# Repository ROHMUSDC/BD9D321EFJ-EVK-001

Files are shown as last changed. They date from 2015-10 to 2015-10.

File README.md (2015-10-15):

# BD9D321EFJ-EVK-001 Design Resource Repository
* Hardware Design Files and Documentation for the ROHM BD9D321EFJ-EVK-001 EVK

----
### Description: 
* BD9D321EFJ is a synchronous buck switching regulator with built-in low on-resistance power MOSFETs
* It is capable of providing current of up to 3 A
* The SLLM (TM) control provides excellent efficiency characteristics in light-load conditions which make the product appropriate for equipment and devices that demand minimal standby power consumption
* External phase compensation circuit is not necessary because this device uses a constant on-time control DC/DC converter with high speed response

----
### Repository Contents
* Application Note Folder: Contains Draft Version of EVK Application Note
* Design Files: Contains Board, Gerber, Schematic, and BOM information for this EVK Board

----
### Where to Purchase?
* http://www.rohm.com/web/global/distribution/-/dinventory/BD9D321EFJ-EVK-101/sample/0

----
### DISCLAIMER
This Technical Data is protected under copyright laws.

ROHM hereby grants you a nonexclusive, nontransferable license to use this Technical Data 
as long as you abide by the terms and conditions of this DISCLAIMER. 

However, you are not authorized to sell, loan, rent, lease, redistribute or license this Technical Data, 
in whole or in part, or in modified form, to anyone.

You may modify this Technical Data to suit your specific applications, 
but the rights to derivative works and said modifications shall belong to ROHM. 

You may make copies of this Technical Data as necessary for internal use only within your company.

In any case, the latest datasheet is considered the final design guideline and represents 
the only actual performance specifications.

ROHM shall not be responsible for ensuring proper application on all computer systems.
This Technical Data is provided AS IS. ROHM makes no guarantees, either implicitly or explicitly, 
regarding its usability, functionality, accuracy, merchantability, or fitness for a specific purpose.

In addition, you shall take full responsibility for the use of any information acquired from this Technical Data. 

ROHM does not assume warranty of any kind arising from the use of this Technical Data. ACCORDINGLY, 
IN NO EVENT SHALL ROHM BE RESPONSIBLE, WHETHER THROUGH CONTRACT OR TORT LIABILITY, 
FOR ANY DAMAGES (INCLUDING BUT NOT LIMITED TO LOST PROFITS OR OTHER INCIDENTAL, CONSEQUENTAL, 
OR PUNITIVE DAMAGES) ARISING OUT OF OR IN CONNECTION WITH THE USE OR APPLICATION OF THIS Technical Data.

Furthermore, this Technical Data is subject to change without notice.

Unless otherwise expressly provided herein, ROHM does not convey any license under patent rights 
or any other intellectual property rights (including those of third parties).

ROHM is not obligated to provide maintenance or support for the Technical Data.

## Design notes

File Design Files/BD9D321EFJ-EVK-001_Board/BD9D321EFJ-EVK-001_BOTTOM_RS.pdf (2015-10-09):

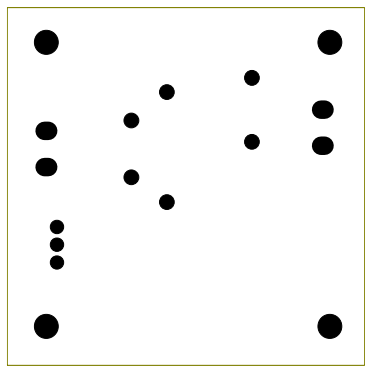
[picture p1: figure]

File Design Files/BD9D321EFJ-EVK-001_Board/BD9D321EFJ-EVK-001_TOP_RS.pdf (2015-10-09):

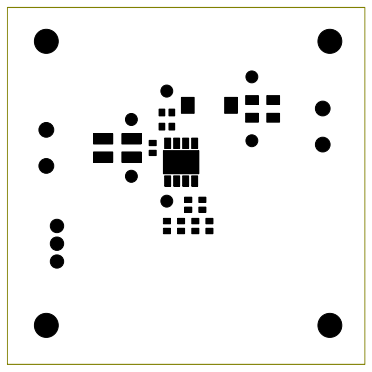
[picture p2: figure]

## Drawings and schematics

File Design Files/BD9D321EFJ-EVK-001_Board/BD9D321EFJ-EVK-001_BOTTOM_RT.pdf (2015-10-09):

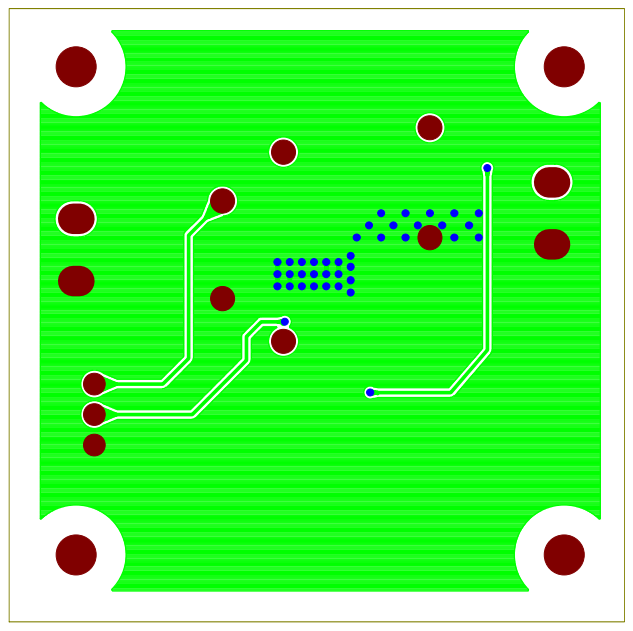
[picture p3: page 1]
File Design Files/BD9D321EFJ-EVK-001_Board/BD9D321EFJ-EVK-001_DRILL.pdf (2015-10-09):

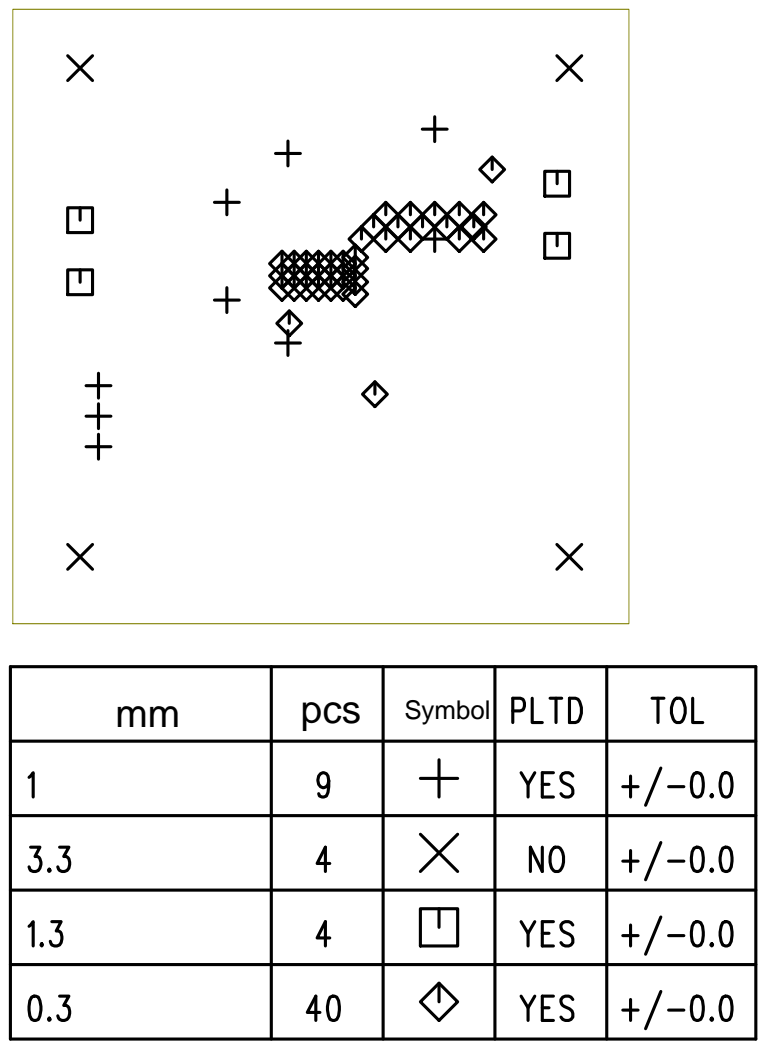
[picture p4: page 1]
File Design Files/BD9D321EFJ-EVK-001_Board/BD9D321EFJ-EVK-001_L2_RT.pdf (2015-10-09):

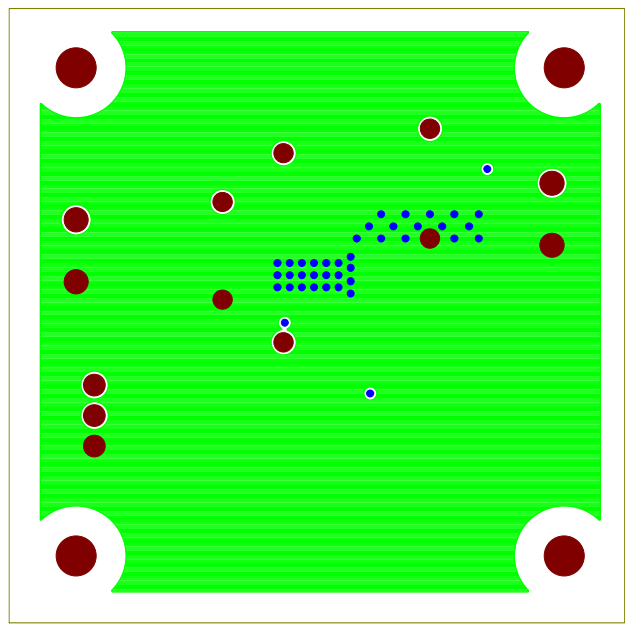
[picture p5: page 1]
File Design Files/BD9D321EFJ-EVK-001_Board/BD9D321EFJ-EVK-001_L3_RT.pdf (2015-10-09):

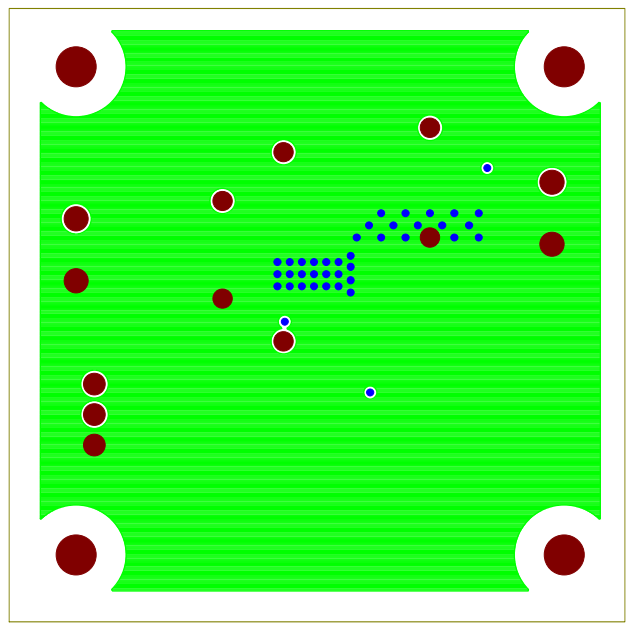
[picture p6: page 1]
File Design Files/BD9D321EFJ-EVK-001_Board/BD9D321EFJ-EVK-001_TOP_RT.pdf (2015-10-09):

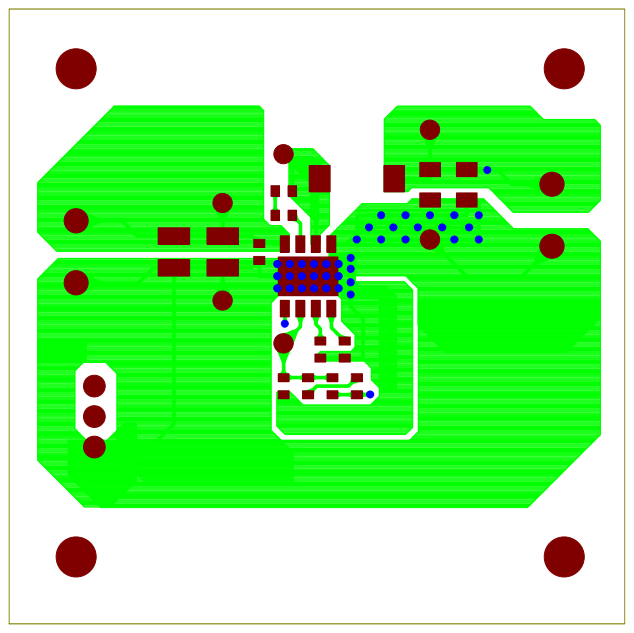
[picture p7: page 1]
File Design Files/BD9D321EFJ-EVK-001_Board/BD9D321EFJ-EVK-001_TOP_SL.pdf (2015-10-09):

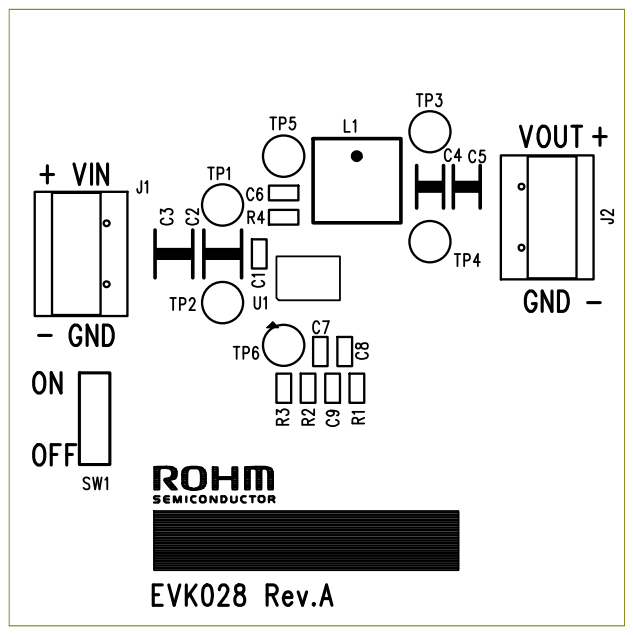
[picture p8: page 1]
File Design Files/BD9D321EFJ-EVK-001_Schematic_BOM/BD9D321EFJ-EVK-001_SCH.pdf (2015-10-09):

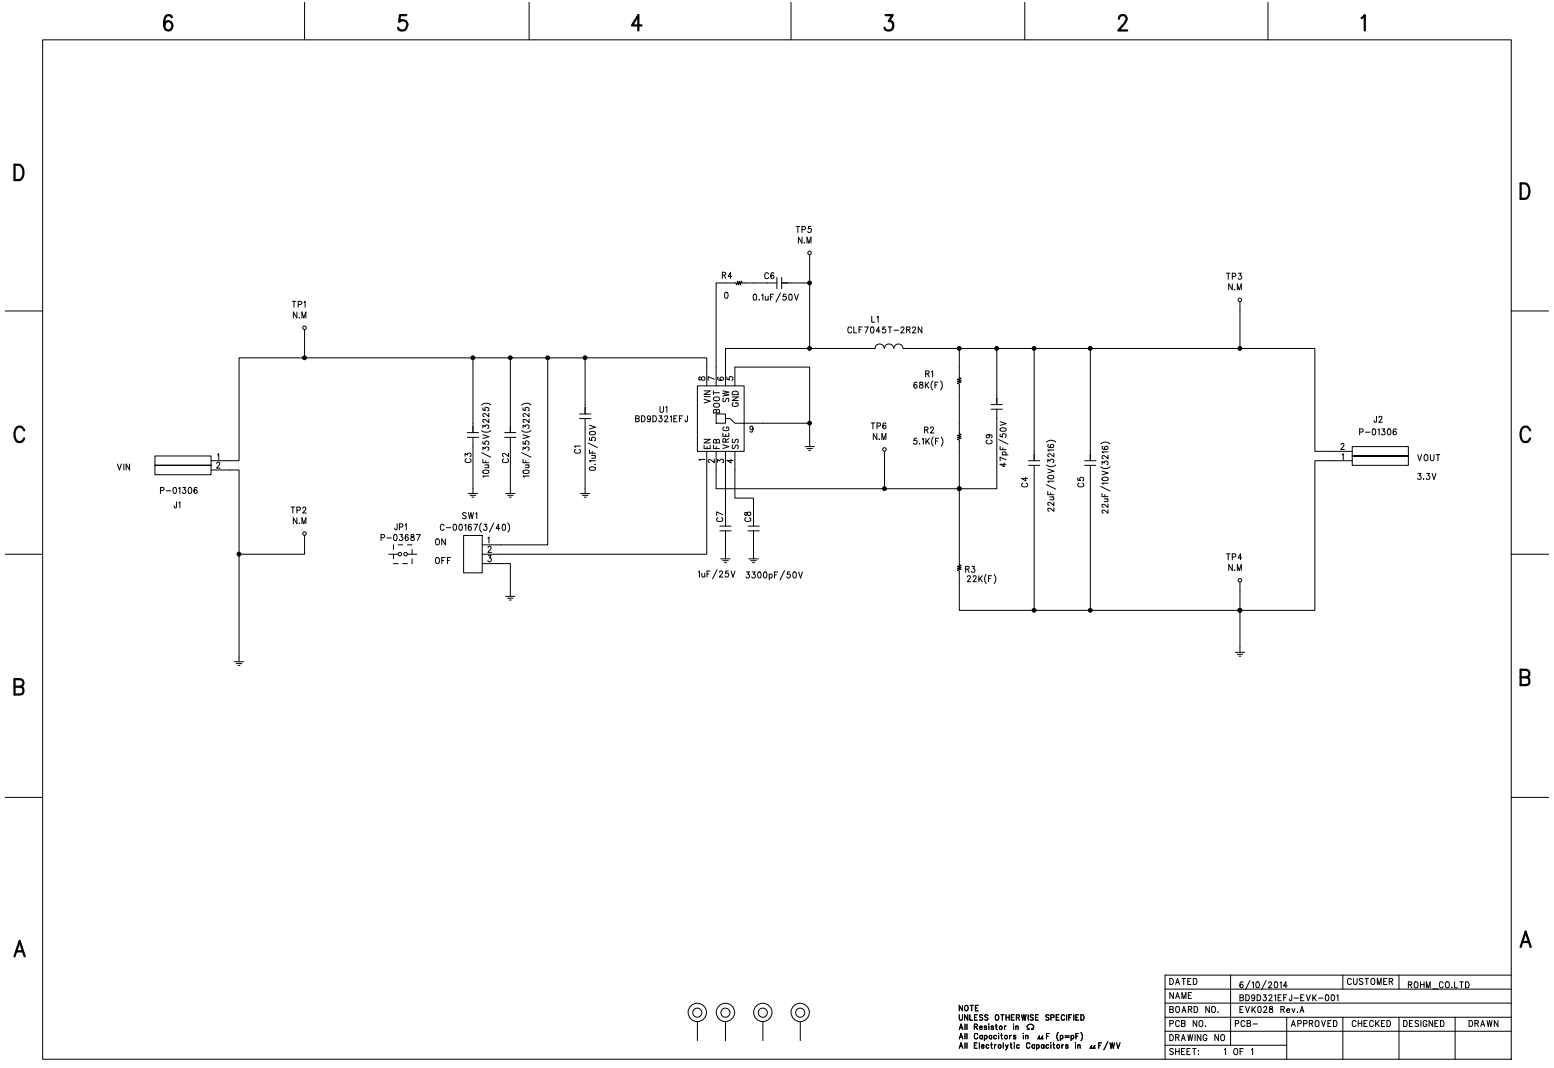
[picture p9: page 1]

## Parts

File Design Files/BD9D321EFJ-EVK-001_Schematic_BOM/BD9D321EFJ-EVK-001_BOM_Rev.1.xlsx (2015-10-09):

BD9D321EFJ-EVK-001 BOM Rev. 1 VIN=5.08V to 18V, VOUT=3.3V |  |  |  |  |  | 2015-06-10
Count | Reference Designator | Type | Value | Description | Manufacturer Part Number | Manufacturer | Configuration (mm)
2 | C1, C6 | Ceramic Capacitor | 0.1µF | 50V, B, ±20% | GRM188B31H104MA92 | MURATA | 1608
2 | C2, C3 | Ceramic Capacitor | 10µF | 35V, B, ±10% | GRM32EB3YA106KA12 | MURATA | 3225
2 | C4, C5 | Ceramic Capacitor | 22µF | 10V, B, ±10% | GRM31CB31A226KE19 | MURATA | 3216
1 | C7 | Ceramic Capacitor | 1µF | 25V, B, ±10% | GRM188B31E105KA75 | MURATA | 1608
1 | C8 | Ceramic Capacitor | 3300pF | 50V, B, ±10% | GRM188B11H332KA01 | MURATA | 1608
1 | C9 | Ceramic Capacitor | 47pF | 50V, CH, ±5% | GRM1882C1H470JA01 | MURATA | 1608
1 | L1 | Inductor | 2.2µH | ±30%, DCR=19mΩmax, 5.5A | CLF7045T-2R2N | TDK | 7269
1 | R1 | Resistor | 68kΩ | 1/10W, 50V, 1% | MCR03ERPF6802 | ROHM | 1608
1 | R2 | Resistor | 5.1kΩ | 1/10W, 50V, 1% | MCR03ERPF5101 | ROHM | 1608
1 | R3 | Resistor | 22kΩ | 1/10W, 50V, 1% | MCR03ERPF2202 | ROHM | 1608
1 | R4 | Resistor | 0Ω | Jumper | MCR03ERPJ000 | ROHM | 1608
1 | SW1 | Pin header | - | 2.54mm × 3 contacts | PH-1x03SG | USECONN | -
1 | U1 | IC | - | Buck DC/DC Converter | BD9D321EFJ | ROHM | HTSOP-J8
2 | J1, J2 | Terminal Block | - | 2 contacts, 15A, 14 to 22AWG | TB111-2-2-U-1-1 | Alphaplus Connectors & Cables | -
1 | - | Jumper | - | Jumper pin for SW1 | MJ254-6BK | USECONN | -
